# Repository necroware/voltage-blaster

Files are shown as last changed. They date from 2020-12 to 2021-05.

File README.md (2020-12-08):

# Voltage Blaster

Voltage Blaster is a very simple circuit, which provides -5V through ISA slot
for systems with power supply which don't provide such voltage. It was created
in cooperation of PhilsComputerLab with Necroware.

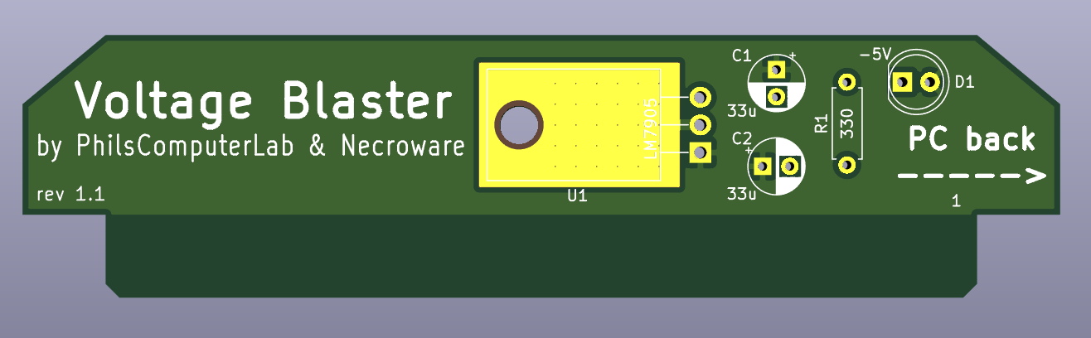
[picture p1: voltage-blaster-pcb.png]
voltage-blaster-pcb


## Why do I need this?

Back in the days of XT and AT compatible computers the standard power supply had
to provide 5V, 12V, -12V and -5V. A lot of hardware, especially sound cards,
needed -5V to work properly. This voltage was provided for the ISA expansion
cards on the pin B5. As time passed, AT systems and compatible power supplies
were replaced by ATX. In the beginning they also provided -5V, but then less and
less expansion cards needed such voltage and as soon as ISA was considered 
obsolete, ATX standard eventually dropped -5V rail requirement. Today it is not
possible to buy a new AT power supply, but ATX power supplies can be used
through an adapter. However, since almost none of the modern ATX power supplies
will provide -5V, you could run into problems, when trying to use an old ISA
expansion card, which needs this voltage. Famous examples are Creative Sound
Blaster 2.0, Pro Audio Spectrum sound cards and many others. This is where the
Voltage Blaster comes into play.

## How does it work?

All voltage pins in the ISA slots are directly connected to each other and to
the PSU. When using a PSU without -5V support, the ISA slot pin B5 is just
floating. The idea behind the Voltage Blaster is very simple. What if one of the
ISA expansion cards will provide -5V and feed it through the ISA slot in
reverse. Well since the ISA slot pin B7 provides -12V, it's just a matter of
using a linear voltage regulator LM7905 and connect its output to the pin B5 of
the ISA slot.

## Bill of materials

Reference  |#  |LCSC   |Description
-----------|---|-------|-------------------------------------
U1         | 1 |C427634| linear voltage regulator LM7905
C1,C2      | 2 |C3314  | electrolytic capacitor 33µF
D1         | 1 |C99697 | light emitting diode (optional)
R1         | 1 |C58608 | resistor 330 Ohm (optional)

Parts D1 and R1 are optional and are only required if you want that the diode is
lighting, when -5V are generated.

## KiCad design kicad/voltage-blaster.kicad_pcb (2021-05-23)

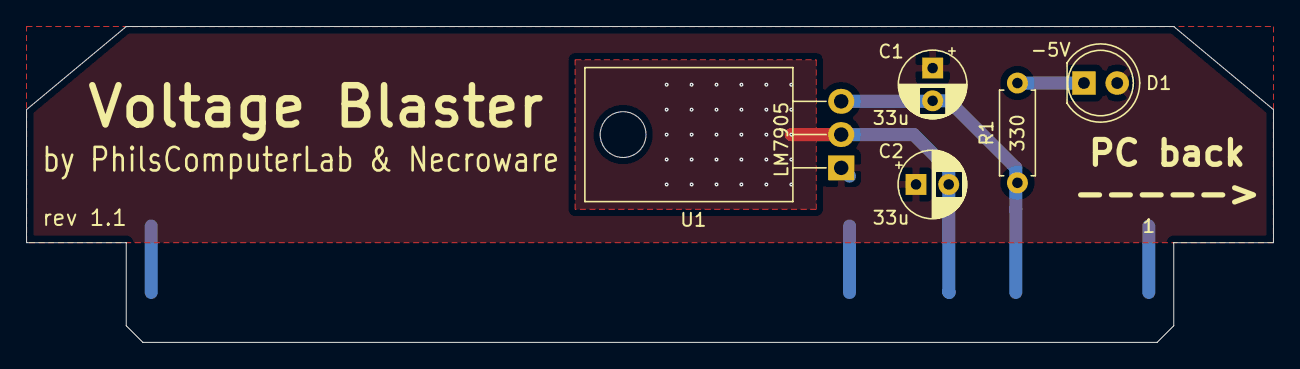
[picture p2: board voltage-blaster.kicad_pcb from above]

Board: 2 copper layers, 95.2 x 24.1 mm, 6 parts (0 on the bottom side), 4 nets.

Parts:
C1, C2: 33u; CP_Radial_D5.0mm_P2.50mm
D1: -5V; LED_D5.0mm
J1: Bus_ISA_8bit; ISA_8BIT_EDGE
R1: 330; R_Axial_DIN0207_L6.3mm_D2.5mm_P7.62mm_Horizontal
U1: LM7905; TO-220-3_Horizontal_TabDown

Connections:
GND: C1.1, C2.1, D1.2, J1.1, J1.10, J1.31, U1.1
unnamed: C1.2, J1.5, R1.1, U1.3
unnamed: C2.2, J1.7, U1.2
unnamed: D1.1, R1.2

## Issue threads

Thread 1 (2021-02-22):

Alternative Idea? ATX Extension Cable Mod

bradmkjr, 2021-02-22:
Instead of taking up a valuable ISA slot on the motherboard, why can't an ATX extension cable be used to inject -5V between the power supply and the motherboard?

https://www.amazon.com/Power-Supply-Motherboard-Extension-Inches/dp/B01MQRBQBI
https://www.amazon.com/Cable-Matters-Motherboard-Power-Extension/dp/B01DV1Z66C

Could the same components be soldered inline on the extension cable or on a smaller board?

Feel free to close this issue, just wanted to share my idea and see what others thought.

Thanks,
Brad

D4no0, 2021-03-13:
This can be done no problem, the question is: will you pay 5x the price of that board to get the extension cables? those connectors tend to be quite expensive.

necroware, 2021-03-15:
I think this is also a good proposal, but it would be a completely different solution for the same problem. So, I think, if we do this, we would create another project. This project is about doing it as an ISA card with all the pros and contras.

Closed 2021-03-15.

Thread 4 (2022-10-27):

Schaltplan des KiCad Projektes unvollständig

chris-kwng, 2022-10-27:
C1 und C2 werden nicht korrekt dargestellt und bei C2 scheint nur ein Pol verbunden.

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

So richtig?

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

Und das ist wirklich kein Problem, wenn ein Netzteil doch die -5V liefert?

chris-kwng, 2022-10-27:
Ne ist ja eine negative Spannung, also so herum, richtig?

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

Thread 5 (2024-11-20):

Confused: LM7905 output to B3 +5v?

skadarnold, 2024-11-20:
Hello! I have been looking at implementing the voltage-blaster to have in a separate project I am working on and was looking over the schematic in KiCad. I am a little confused about how it works though, or wondering if there is an error.

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

When looking at this the +12v line goes into the LM7905, but then the output connects to the VCC instead of the -5v. The readme seems to state that it connects to pin B5 but the schematic shows B3.

Just hoping to clear this up so I understand what I am doing with this.

skadarnold, 2024-12-20:
I am still interested in this question. Maybe there is an error with KiCad and the repo files?

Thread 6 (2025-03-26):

How fast does the -5V line start?

tpimh, 2025-03-26:
From [this post](https://electronics.stackexchange.com/a/57378/69142) (emphasis mine):

> -5V was the back-bias voltage for 3-rail DRAMs, in the era of 16kbit DRAMs. These used 5V for the interface, 12V to power the storage, and -5V to provide negative bias to the chip substrate. Without -5V, all 16384 storage transistors turned on at once, pretty much shorting the 12V supply to ground and destroying the chip.
>
> **You needed to ensure the -5V supply was working _before_ starting the 12V supply.** However as it supplied a bias voltage, it didn't need to source a great deal of current; 5ma was enough for a whole 64k memory! (the 12V supply was somewhere close to an amp)

Also, there's another curios thing in this post: -12V requirement of close to 1A (no idea what it can be used for other than RS232). Modern ATX PSUs can't usually provide more than 100mA on the -12V rail. So possibly, an optional -12V generator circuit can also be added to this design?

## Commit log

2020-11-23 Regenerated gerber files
    [voltage-blaster-B_Cu.gbr, voltage-blaster-B_Mask.gbr, voltage-blaster-B_Paste.gbr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]
2020-12-08 Remove gerber files from the project
    [voltage-blaster-B_Cu.gbr, voltage-blaster-B_Mask.gbr, voltage-blaster-B_Paste.gbr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]
2020-12-08 Add some markings on the back side.
    This is actually not necessary, but having this markings there will
    enforce JLCPCB to print their serial number on the back side as well
    [voltage-blaster.kicad_pcb]
2020-12-08 Add BOM to readme
2020-12-08 Add LCSC parts numbers to the schema
    [voltage-blaster.kicad_pcb, voltage-blaster.sch]
2021-02-24 Switch to CC0 License
2021-05-23 Improved PCB layout
    - removed solder mask on LM7905 cooling area
    - increased cooling area on the back side
    - added micro vias for better thermal transport
    - removed unused socket pins
    [voltage-blaster.kicad_pcb]
2021-05-23 Remove X2 option from gerber settings
    [voltage-blaster.kicad_pcb]
2021-05-23 Set PCB revision to 1.1
    [voltage-blaster.kicad_pcb]
